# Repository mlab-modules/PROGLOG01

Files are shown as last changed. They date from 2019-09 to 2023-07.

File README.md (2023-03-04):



# PROGLOG01B - Small low-power open-source tool chain compatible FPGA

<!--- Lead --->
Module with a small programmable gate-array [ICE40UP5K](https://www.latticesemi.com/en/Products/FPGAandCPLD/iCE40UltraPlus).
<!--- ELead --->

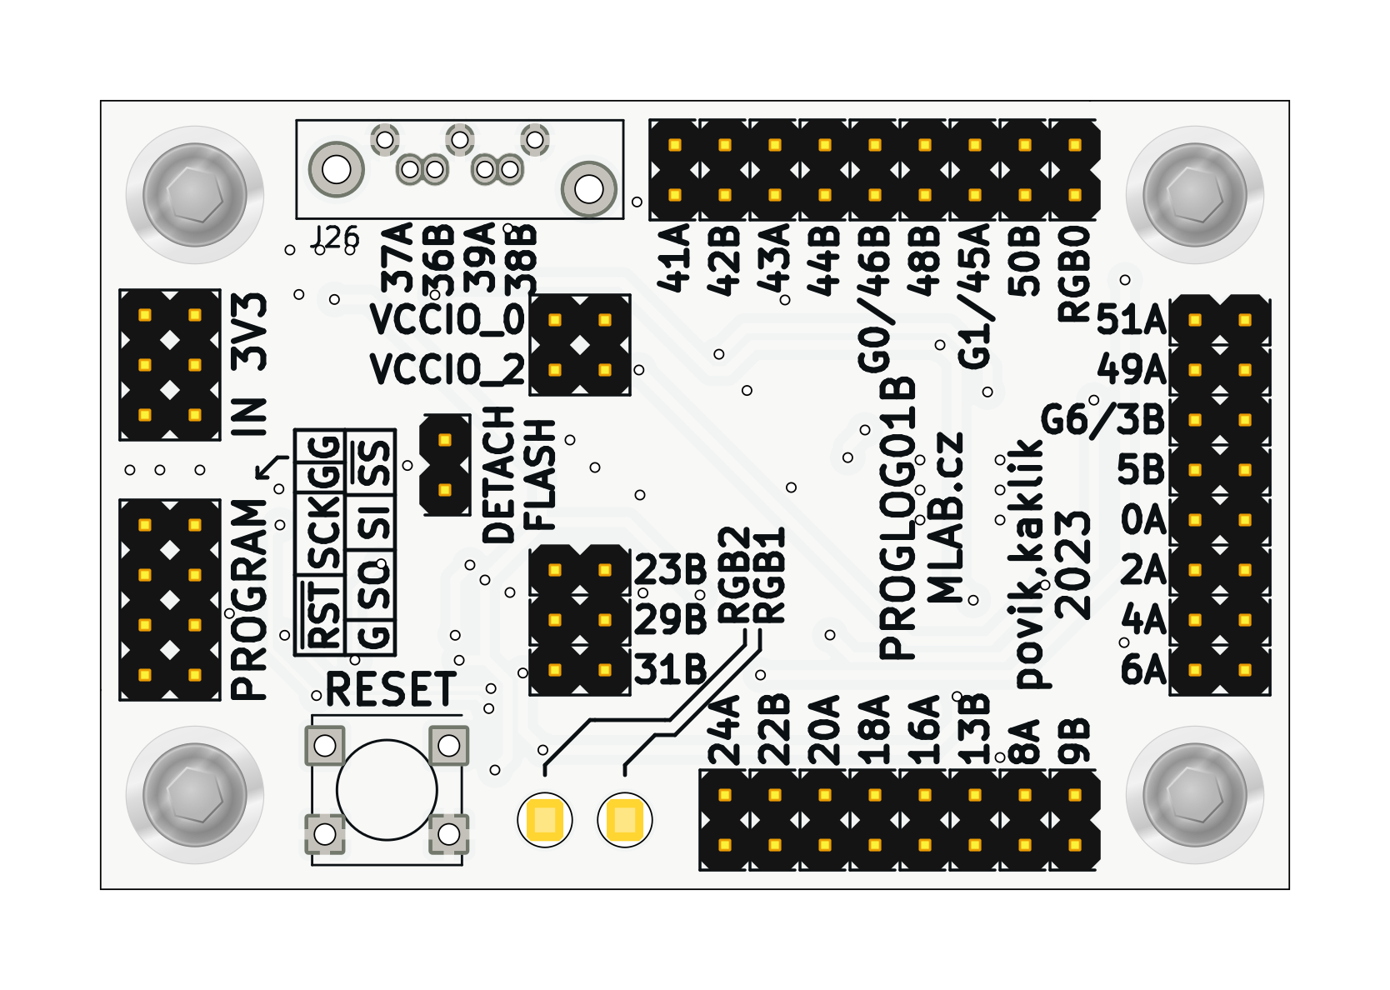
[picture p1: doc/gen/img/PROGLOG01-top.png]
PROGLOG01B top side

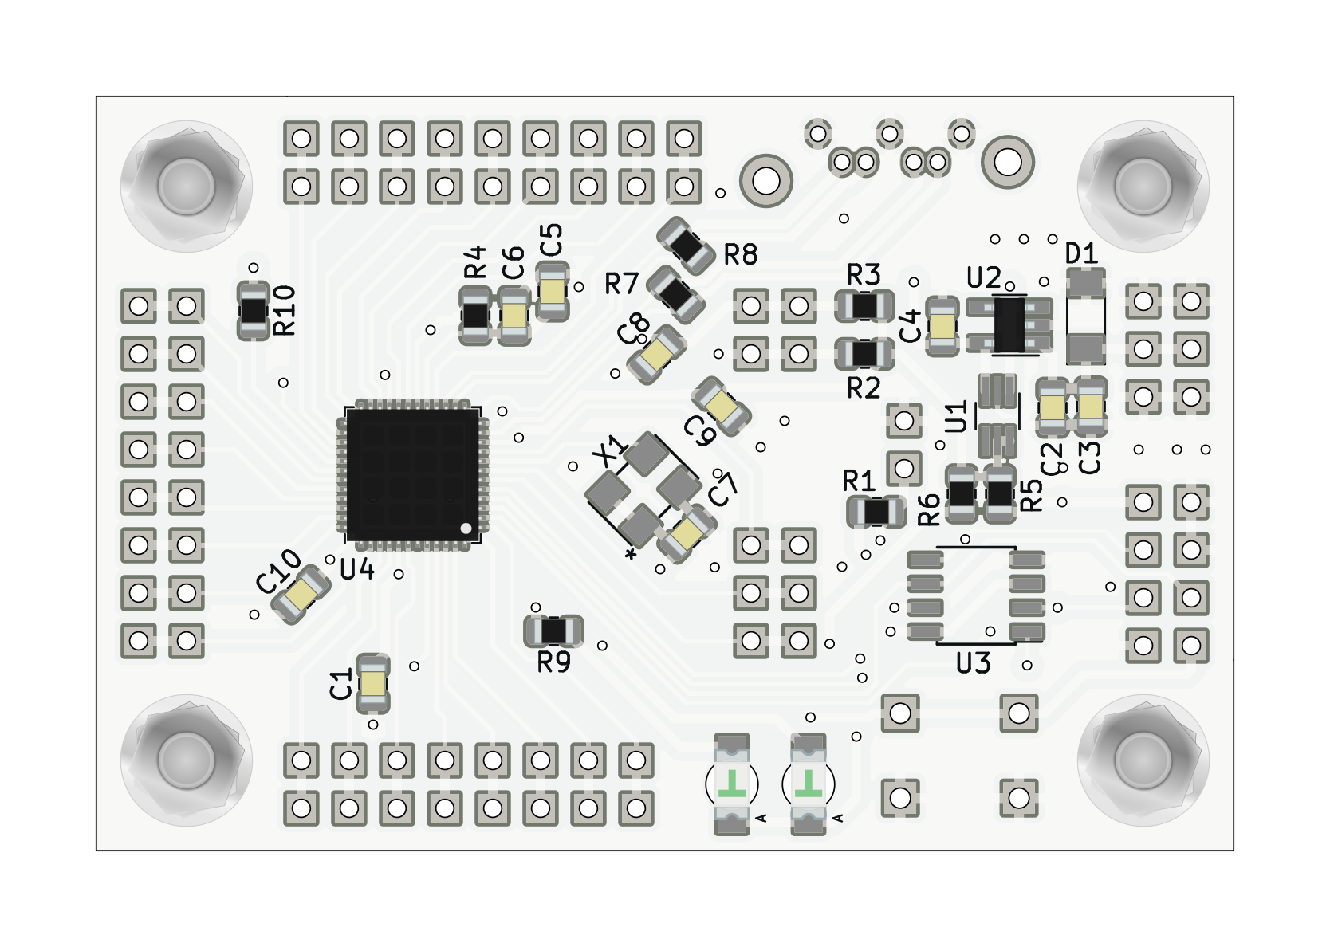
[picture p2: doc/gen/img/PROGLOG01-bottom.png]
PROGLOG01B bottom side


The FPGA module compatible with fully open source toolchains like [symbiflow](https://symbiflow.github.io/).

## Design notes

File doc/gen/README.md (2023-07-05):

# PCB

Board size: 60.45x40.13 mm (2.38x1.58 inches)

- This is the size of the rectangle that contains the board
- Thickness: 1.6 mm (63 mils)
- Material: FR4
- Finish: None
- Layers: 2
- Copper thickness: 35 µm

Solder mask: TOP / BOTTOM

- Color: Green

Silk screen: TOP / BOTTOM

- Color: White

Stackup:

| Name | Type | Color | Thickness | Material | Epsilon_r | Loss tangent |
|---|---|---|---|---|---|---|
| F.SilkS | Top Silk Screen | | | | | |
| F.Paste | Top Solder Paste | | | | | |
| F.Mask | Top Solder Mask | | 10 | | | |
| F.Cu | copper | | 35 | | | |
| dielectric 1 | core | | 1510 | FR4 | 4.5 | 0.020 |
| B.Cu | copper | | 35 | | | |
| B.Mask | Bottom Solder Mask | | 10 | | | |
| B.Paste | Bottom Solder Paste  | | | | | |
| B.SilkS | Bottom Silk Screen | | | | | |

# Important sizes

Clearance: 0.2 mm (8 mils)

Track width: 0.25 mm (10 mils)

- By design rules: 0.25 mm (10 mils)

Drill: 0.5 mm (20 mils)

- Vias: 0.5 mm (20 mils) [Design: 0.4 mm (16 mils)]
- Pads: 0.85 mm (33 mils)
- The above values are real drill sizes, they add 0.1 mm (4 mils) to plated holes (PTH)

Via: 0.8/0.4 mm (31/16 mils)

- By design rules: 0.4/0.3 mm (16/12 mils)
- Micro via: yes [0.2/0.1 mm (8/4 mils)]
- Buried/blind via: yes
- Total: 58 (thru: 58 buried/blind: 0 micro: 0)

Outer Annular Ring: 0.13 mm (5 mils)

- By design rules: 0.13 mm (5 mils)

Eurocircuits class: 6B
- Using min drill 0.5 mm for an OAR of 0.13 mm

# General stats

Components count: (SMD/THT)

- Top: 0/38 (THT)
- Bottom: 27/1 (SMD + THT)

Defined tracks:

- 0.25 mm (10 mils)
- 0.5 mm (20 mils)

Used tracks:

- 0.25 mm (10 mils) (244) defined: yes
- 0.4 mm (16 mils) (14) defined: no
- 0.5 mm (20 mils) (217) defined: yes

Defined vias:

Used vias:

- 0.8/0.4 mm (31/16 mils) (Count: 58, Aspect: 2.0 A) defined: no

Holes (excluding vias):

- 0.74 mm (29 mils) (7)
- 0.89 mm (35 mils) (76)
- 1.0 mm (39 mils) (4)
- 1.35 mm (53 mils) (2)
- 2.7 mm (106 mils) (2)
- 3.0 mm (118 mils) (4)

Oval holes:

Drill tools (including vias and computing adjusts and rounding):

- 0.5 mm (20 mils) (58)
- 0.85 mm (33 mils) (7)
- 1.0 mm (39 mils) (76)
- 1.1 mm (43 mils) (4)
- 1.45 mm (57 mils) (2)
- 2.7 mm (106 mils) (2)
- 3.1 mm (122 mils) (4)

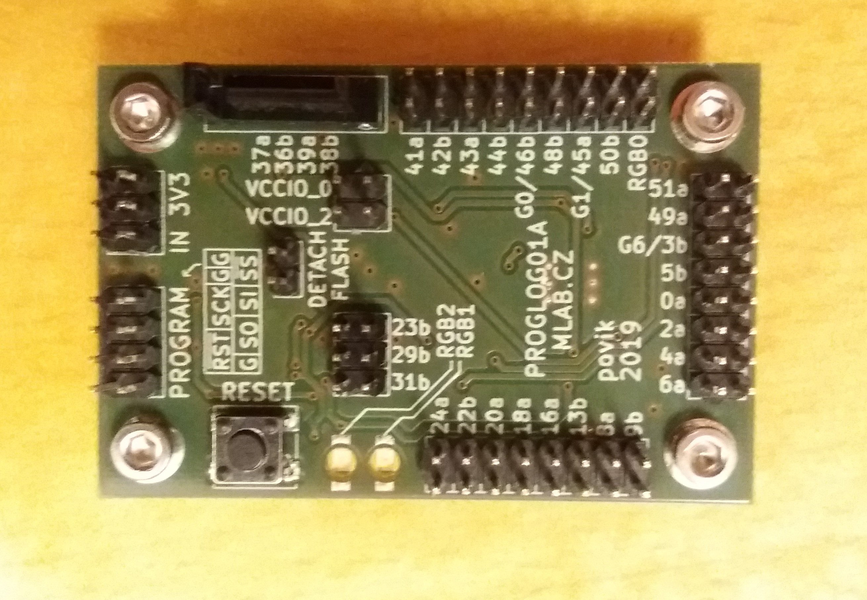
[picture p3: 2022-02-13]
doc/img/PROGLOG01A_top_big.jpg

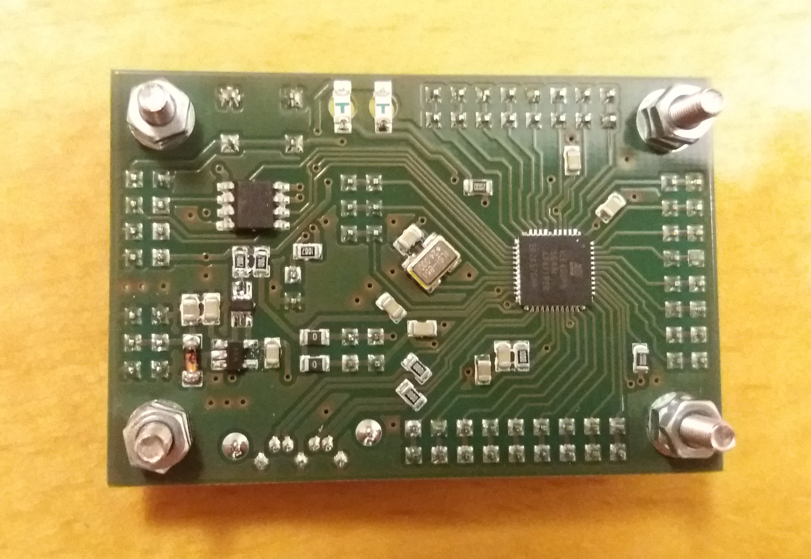
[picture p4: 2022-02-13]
doc/img/PROGLOG01A_bot_big.jpg

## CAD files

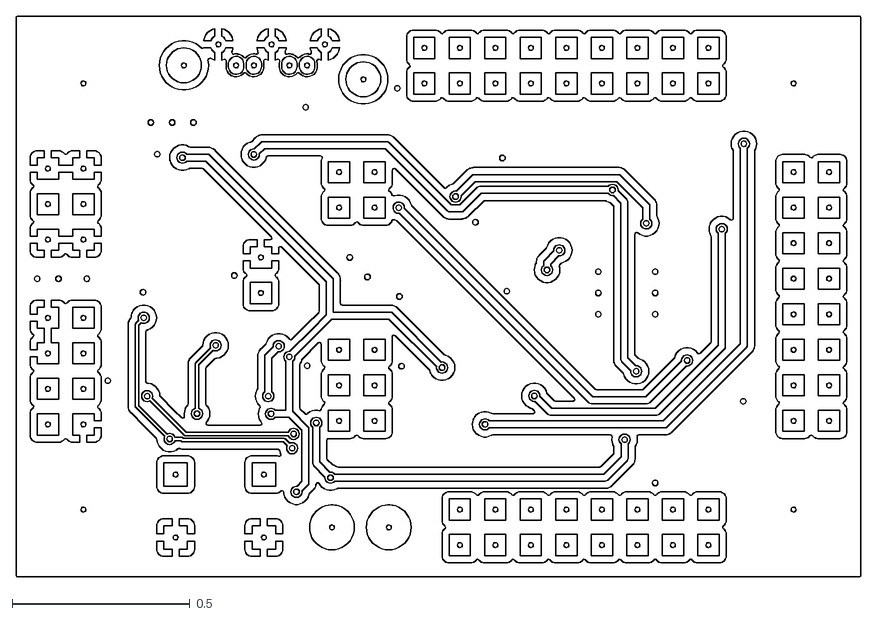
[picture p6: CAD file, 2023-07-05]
doc/gen/dxf/PROGLOG01-F_Cu.dxf
2.38 x 1.58

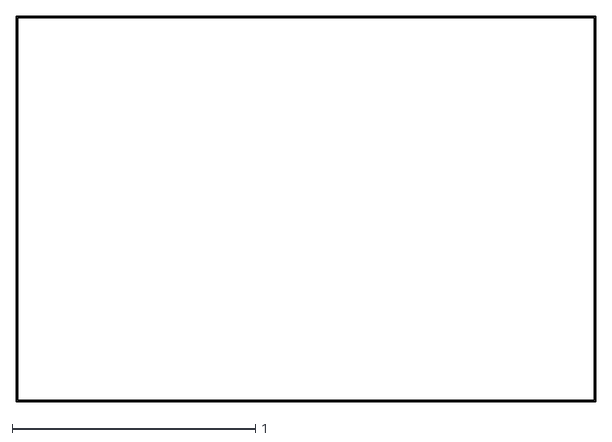
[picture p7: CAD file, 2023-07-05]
doc/gen/dxf/PROGLOG01-Edge_Cuts.dxf
2.39 x 1.59

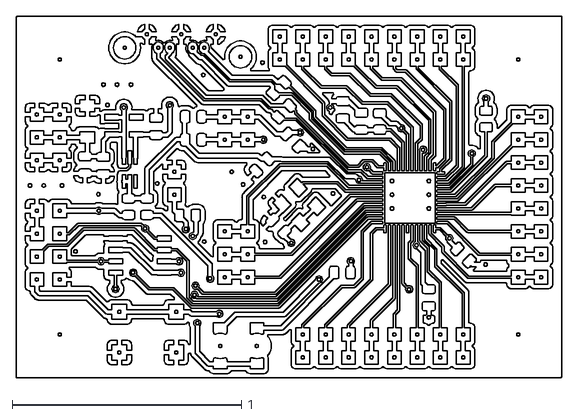
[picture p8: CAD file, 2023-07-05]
doc/gen/dxf/PROGLOG01-B_Cu.dxf
2.38 x 1.58

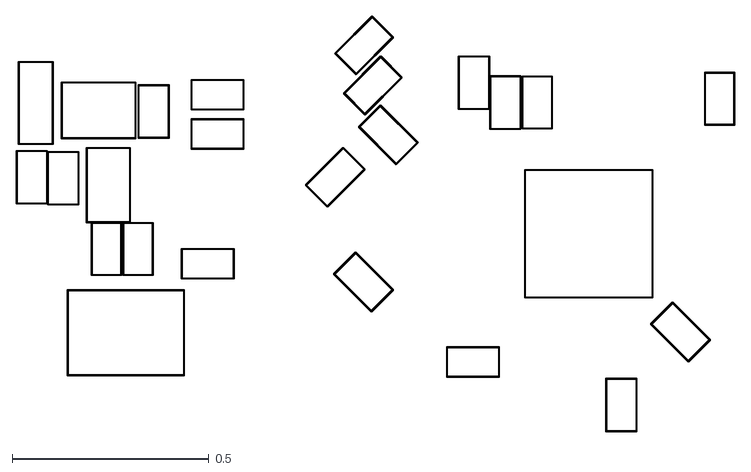
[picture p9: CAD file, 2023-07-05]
doc/gen/dxf/PROGLOG01-B_Courtyard.dxf
1.83 x 1.06

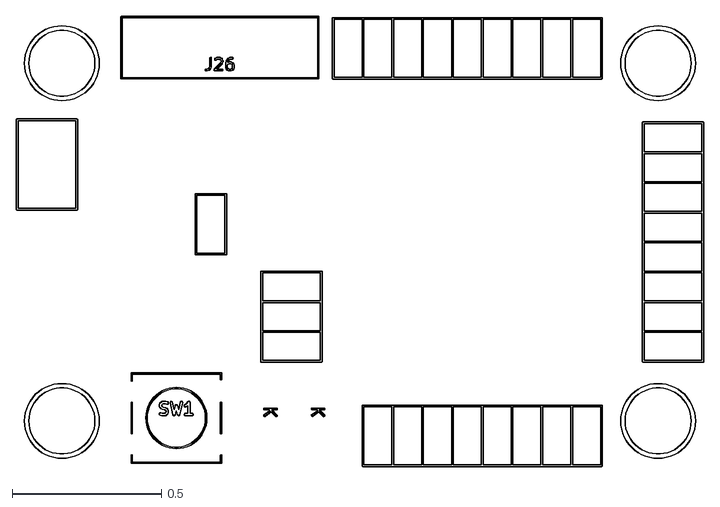
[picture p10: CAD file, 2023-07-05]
doc/gen/dxf/PROGLOG01-F_Fab.dxf
2.31 x 1.51

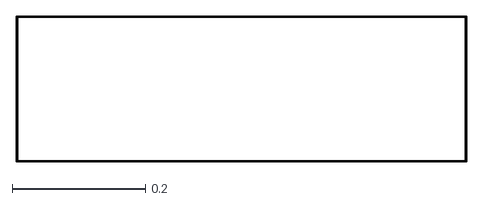
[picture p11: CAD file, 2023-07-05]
doc/gen/dxf/PROGLOG01-F_Courtyard.dxf
0.675 x 0.219

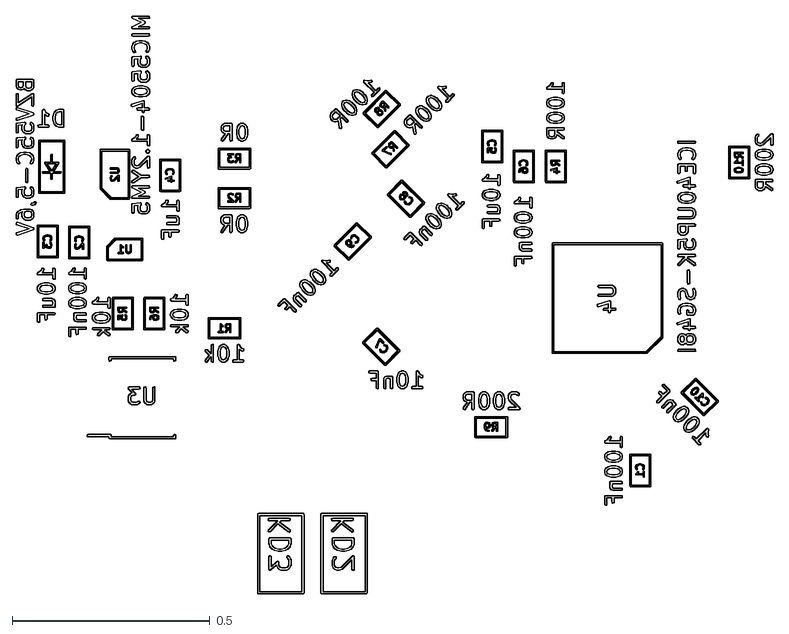
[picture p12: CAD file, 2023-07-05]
doc/gen/dxf/PROGLOG01-B_Fab.dxf
1.92 x 1.46

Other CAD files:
doc/gen/dxf/PROGLOG01-Margin.dxf
doc/gen/dxf/PROGLOG01-B_Mask.dxf
doc/gen/dxf/PROGLOG01-B_Paste.dxf
doc/gen/dxf/PROGLOG01-B_Silkscreen.dxf
doc/gen/dxf/PROGLOG01-F_Mask.dxf
doc/gen/dxf/PROGLOG01-F_Paste.dxf
doc/gen/dxf/PROGLOG01-F_Silkscreen.dxf

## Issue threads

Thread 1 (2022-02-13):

Prohozené signály u Flash paměti

kaklik, 2022-02-13:
Je potřeba zkontrolovat, jestli je to opravené i v layoutu a vytvořit revizi B.

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

povik, 2022-02-13:
Neni to opravené.

kaklik, 2022-11-16:
Pokusil jsem se v [datasheetu](https://www.latticesemi.com/-/media/LatticeSemi/Documents/DataSheets/iCE/FPGA-DS-02008-1-9-iCE40-UltraPlus-Family-Data-Sheet.ashx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) najít, jaký je pinout konfiguračního SPI rozhraní, které má být připojeno k SPI flash.

Nepodařilo se mi však najít více než tohle, což neobjasňuje proč jsou nyní piny zapojeny špatně. Současné zapojení ale odpovídá popiskům nožiček na schématických značkách. Tudíž očekávám že k opravě chyby je potřeba opravit schematickou značku FPGA, neboť schematická značka SPI flash je správně. To jsem již podle datasheetu zkontroloval.

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

Chěl jsem to opravit, aby bylo možné vyrobit více kusů modulů a celý další vývoj nestál pouze na existujících dvou kusech.

kaklik, 2023-02-19:
@povik  Tak jsem to myslím si opravil. Mohl bys akorát prosím zkontrolovat, že je to opravené dobře? Na fotografii totiž jsou celkem tři provizorní drátky, ale našel jsem jen dvě prohozená místa. Třetí myslím vede na stejný pin jako původní cestička. To byla nějaká chyba při změně zapojení?

povik, 2023-02-20:
Jo, prohozené ve schématu 01A jsou jen dva dráty u paměti (MISO/MOSI). Že jsou na tom operovaném kusu tři drátky, bude kvůli nějakému omylu při přepojování.

> Tudíž očekávám že k opravě chyby je potřeba opravit schematickou značku FPGA, neboť schematická značka SPI flash je správně.

Jak tohle dopadlo? Čekám, že to byla chyba ve schématu, né ve značce, tak si to pamatuju.

kaklik, 2023-02-20:
> > Tudíž očekávám že k opravě chyby je potřeba opravit schematickou značku FPGA, neboť schematická značka SPI flash je správně.
>
> Jak tohle dopadlo? Čekám, že to byla chyba ve schématu, né ve značce, tak si to pamatuju.

S tímhle to teď je tak, že ta schématická značka FPGA je neopravená. Tj. je pravděpodobně špatně název pinu ve schématické značce. Kontroloval jsem to podle čísla pinu, které je myslím si správně.

povik, 2023-02-20:
> S tímhle to teď je tak, že ta schématická značka FPGA je neopravená. Tj. je pravděpodobně špatně název pinu ve schématické značce. Kontroloval jsem to podle čísla pinu, které je myslím si správně.

Ne, já myslim, že značka je správně. Jen je matoucí, že pin SI/SO na součástce hradlovýho pole znamená Serial In/Out, nikoliv Slave In/Out, takže se to s pamětí musí zapojit křížem. To je původ toho omylu ve schématu.

kaklik, 2023-02-20:
> Ne, já myslim, že značka je správně. Jen je matoucí, že pin SI/SO na součástce hradlovýho pole znamená Serial In/Out, nikoliv Slave In/Out, takže se to s pamětí musí zapojit křížem. To je původ toho omylu ve schématu.

Aha, tak to je opravdu matoucí.  To by si možná zasloužilo nějakou poznámku do schéma. Protože se to děsně blbě ověřuje. V datasheetu jsem totiž tohle našel jen na jednom místě a nedošlo mi z toho, že to není chyba v datasheetu.

Closed 2023-02-19.

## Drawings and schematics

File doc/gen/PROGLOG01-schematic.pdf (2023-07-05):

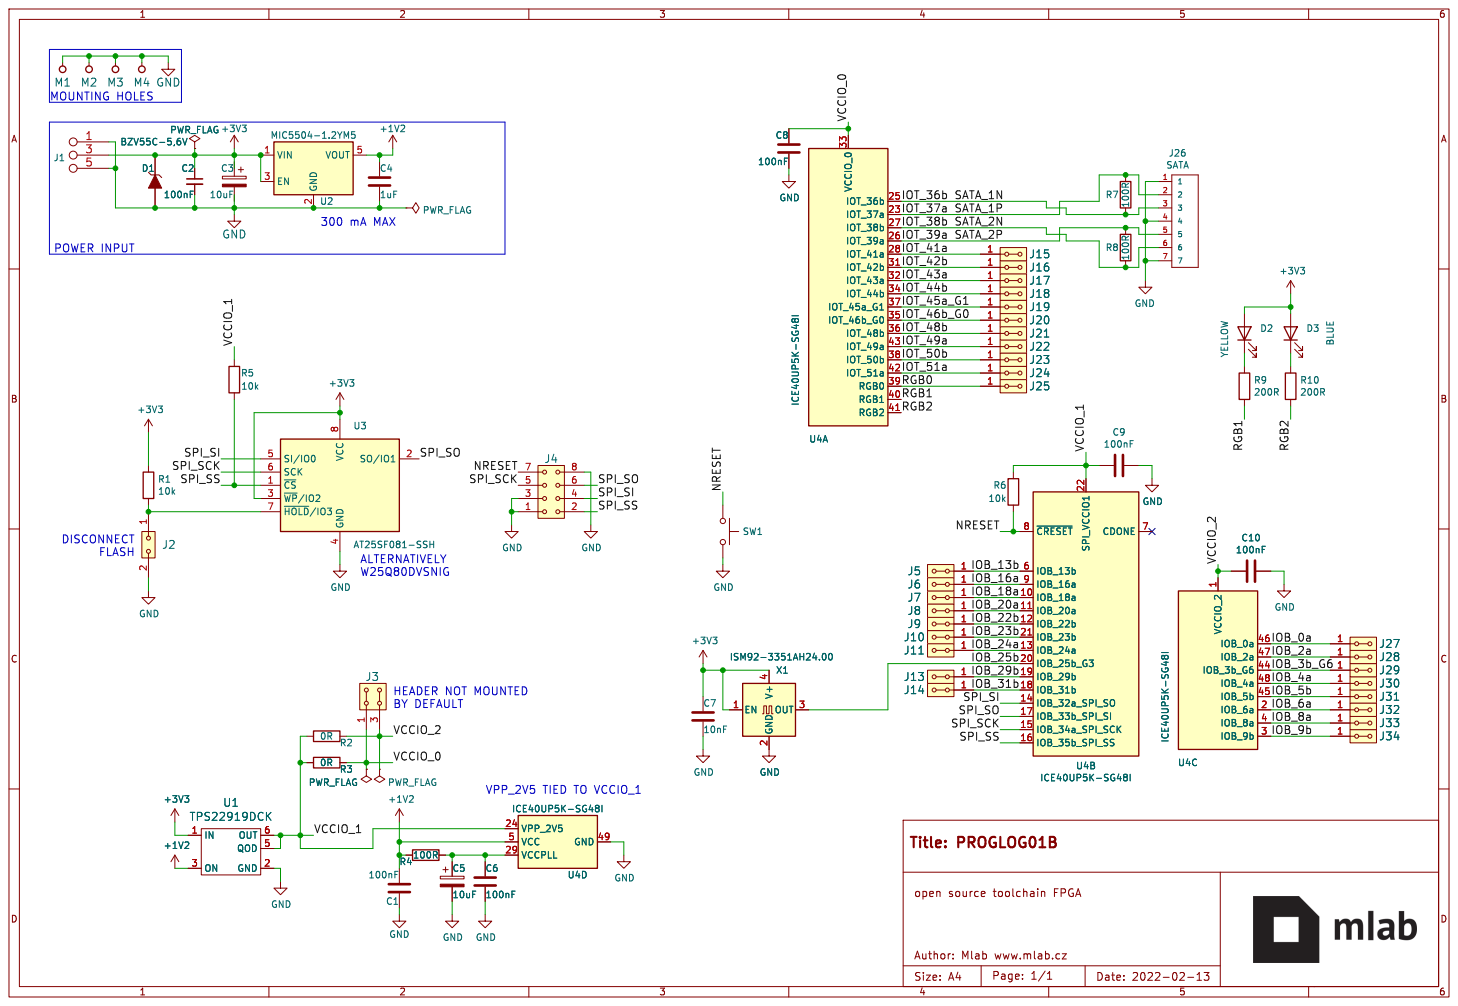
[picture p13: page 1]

POWER INPUT MOUNTING HOLES

4 SI/IO0 5 SCK 6 ~{HOLD}/IO3 7 VCC

VPP_2V5 TIED TO VCCIO_1 HEADER NOT MOUNTED

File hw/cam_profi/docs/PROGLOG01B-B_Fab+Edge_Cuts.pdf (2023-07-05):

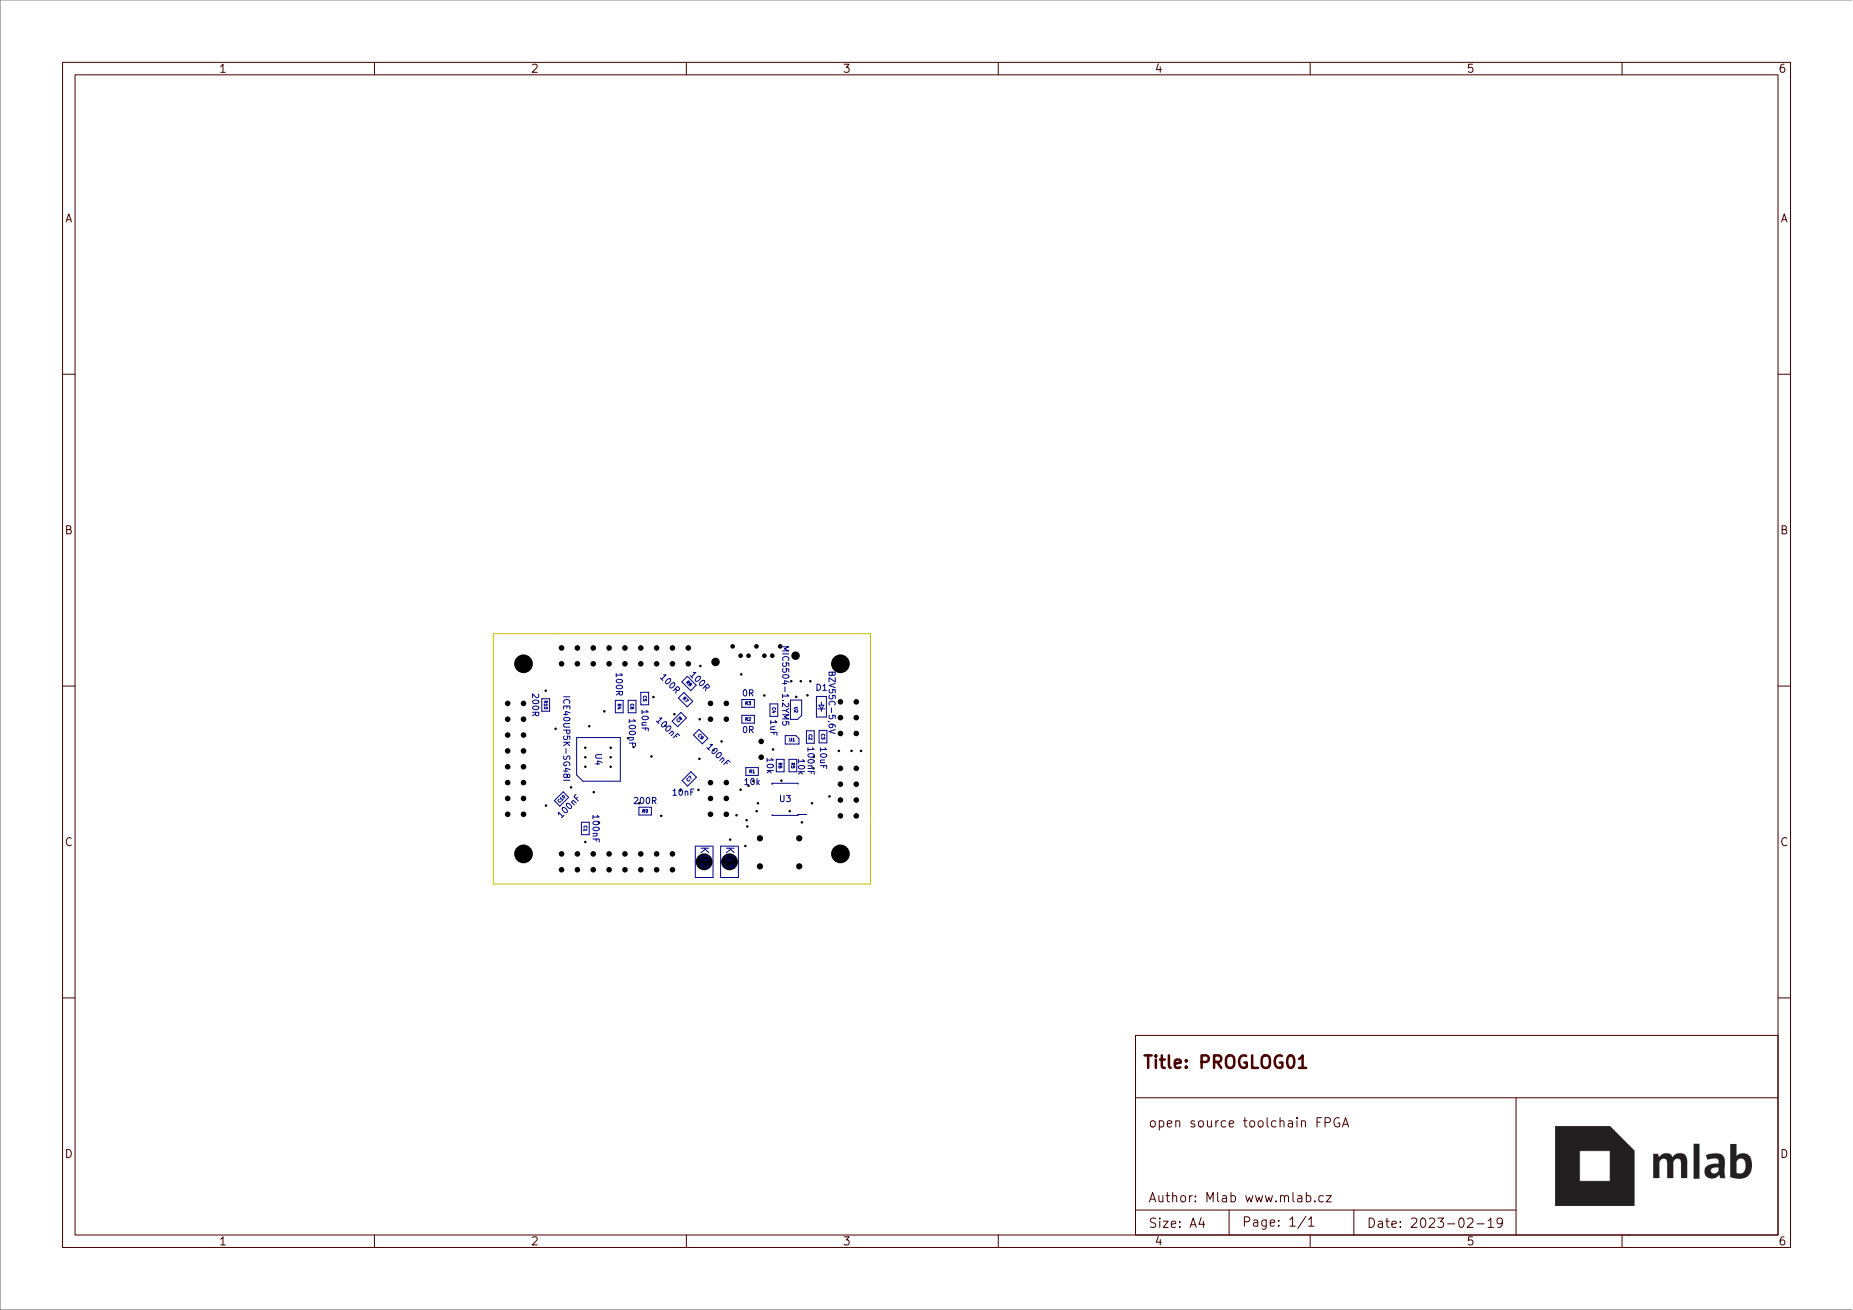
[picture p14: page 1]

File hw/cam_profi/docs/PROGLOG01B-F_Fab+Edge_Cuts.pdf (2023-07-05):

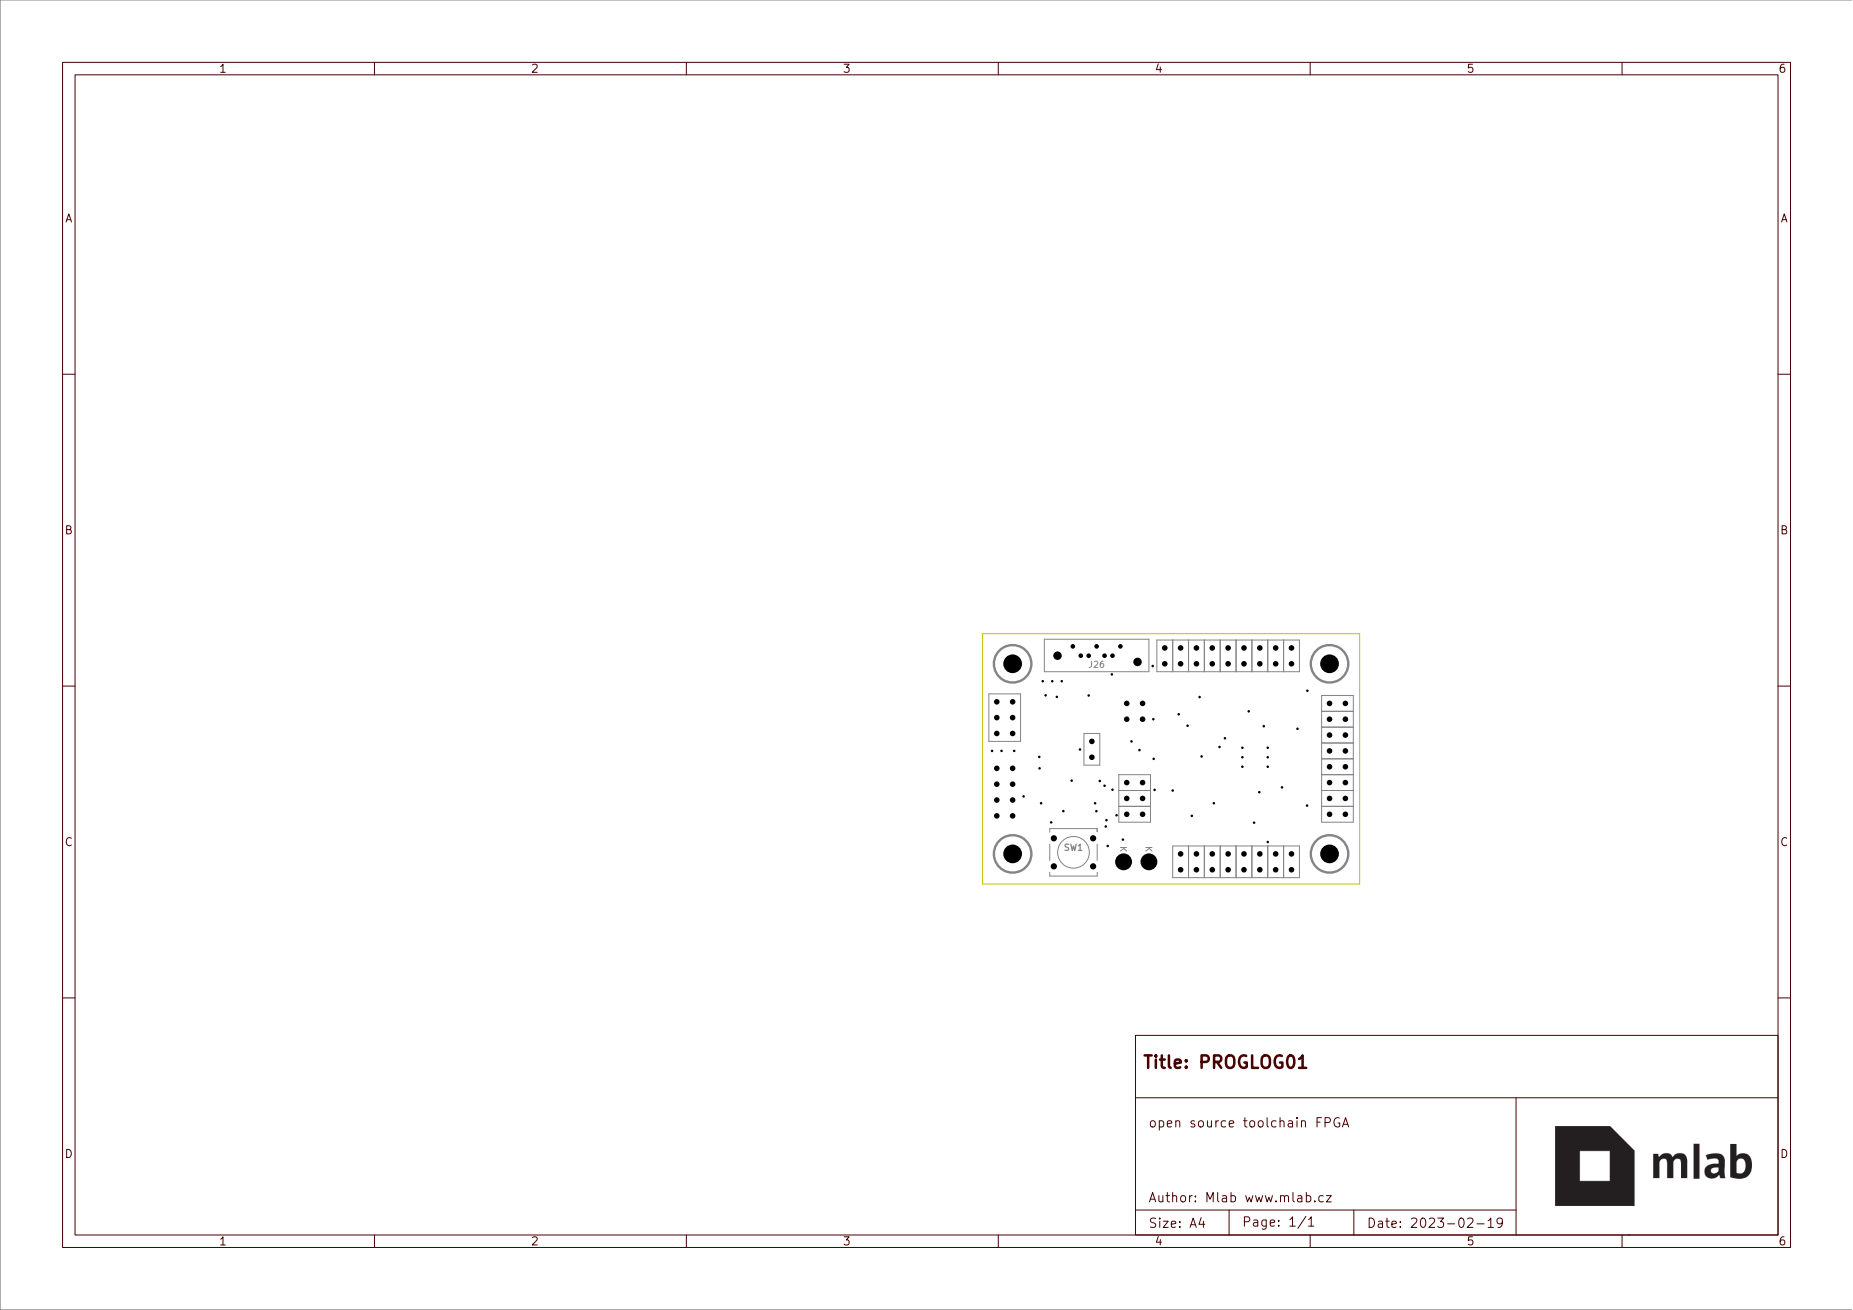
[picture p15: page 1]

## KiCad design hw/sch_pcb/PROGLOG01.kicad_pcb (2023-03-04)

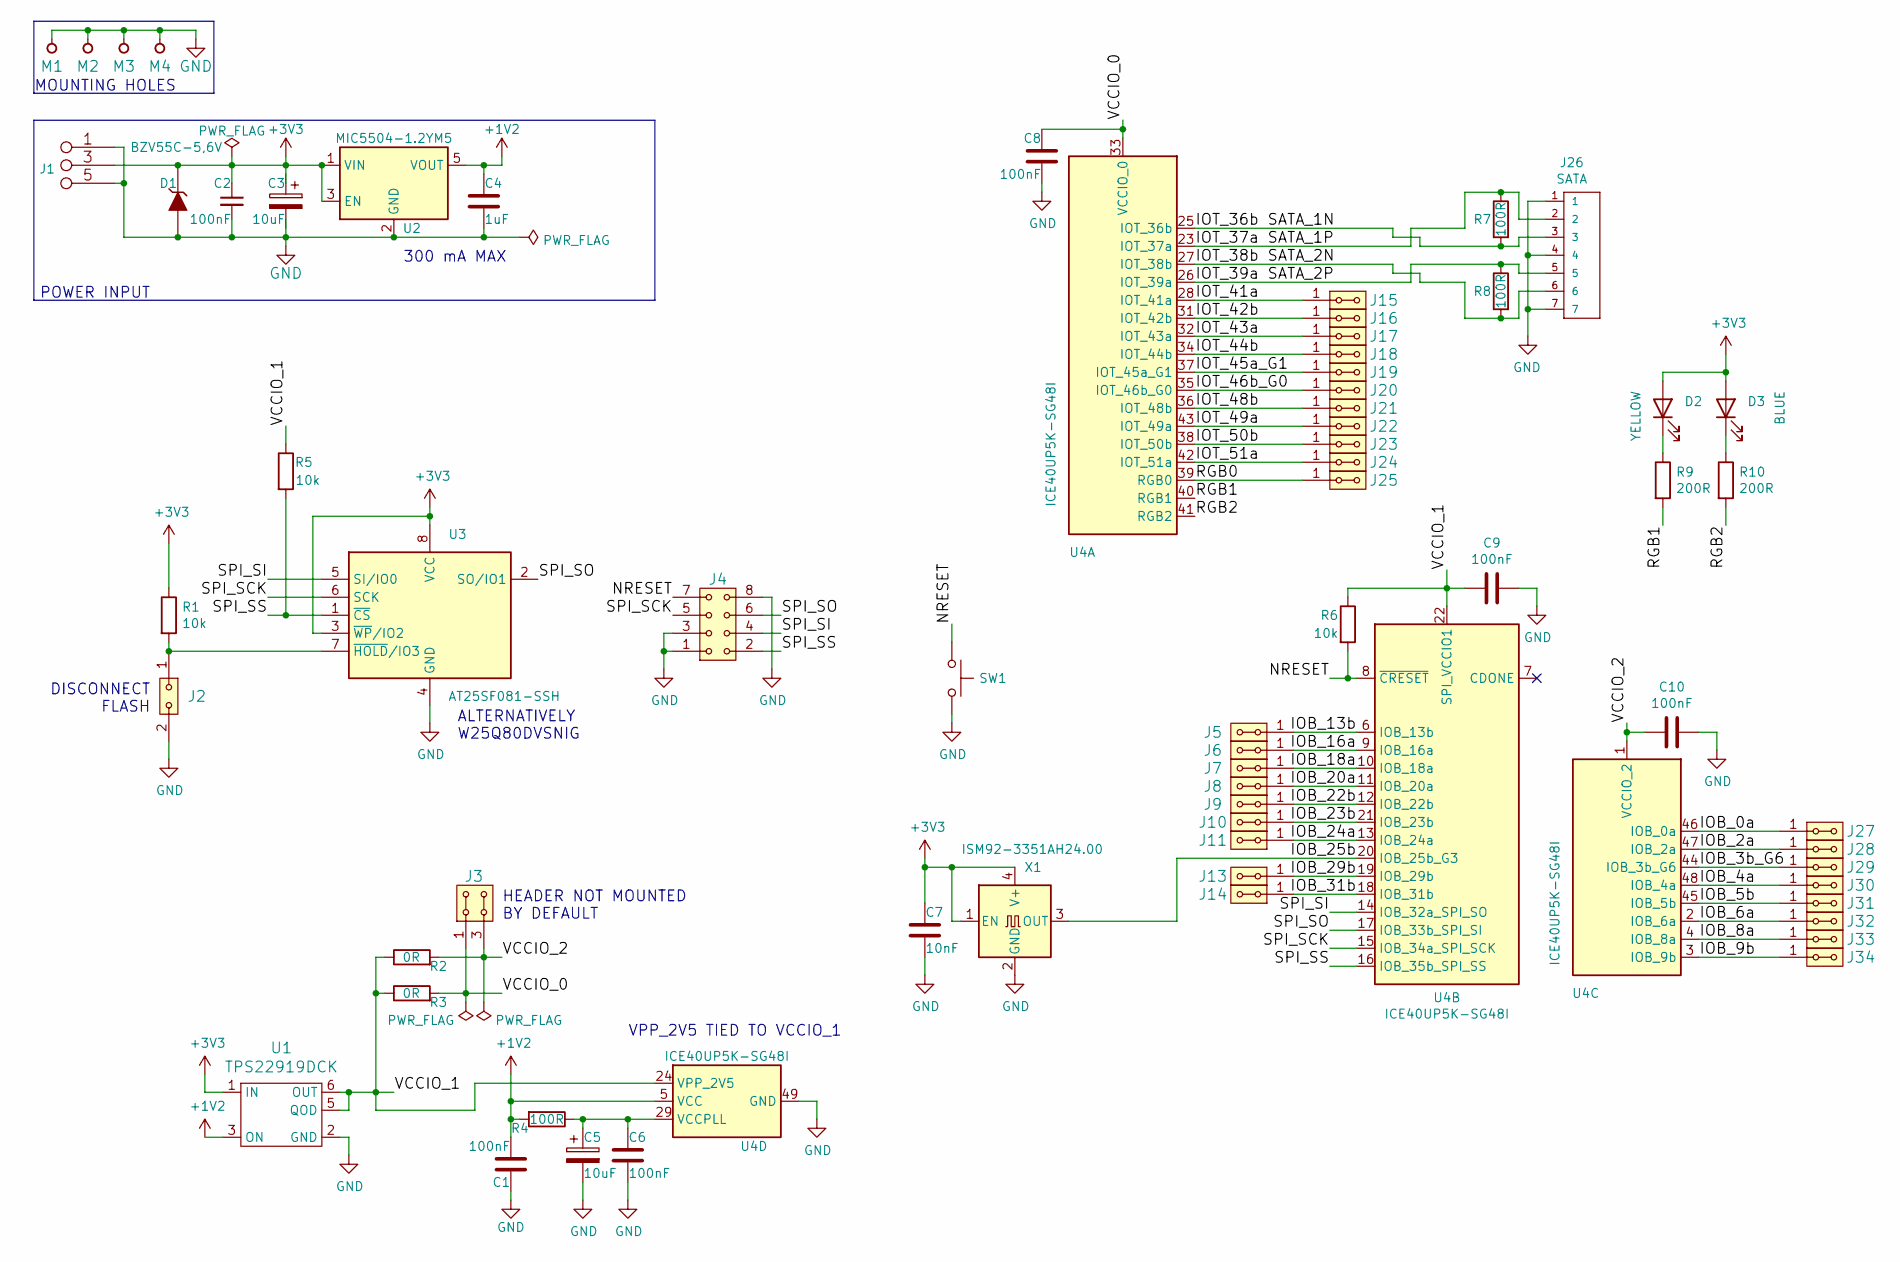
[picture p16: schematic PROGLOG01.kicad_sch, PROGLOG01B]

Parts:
C1, C2, C6, C8, C9, C10: 100nF; C_0805_2012Metric
C3, C5: 10uF; C_0805_2012Metric
C4: 1uF; C_0805_2012Metric
C7: 10nF; C_0805_2012Metric
D1: BZV55C-5,6V; Diode-MiniMELF_Standard
D2: YELLOW; LED_1206
D3: BLUE; LED_1206
J1: JUMP_3X2; Straight_2x03
J2: HEADER_2x01; Straight_2x01
J3: HEADER_2x02_PARALLEL; Straight_2x02
J4: HEADER_2x04; Straight_2x04
J5, J6, J7, J8, J9, J10, J11, J13, J14, J15, J16, J17, J18, J19, J20, J21, J22, J23, J24, J25, J27, J28, J29, J30, J31, J32, J33, J34: HEADER_2x01_PARALLEL; Straight_2x01
J26: SATA; MOLEX_67491-1030
M1, M2, M3, M4: HOLE; MountingHole_3mm
R1, R5, R6: 10k; R_0805_2012Metric
R2, R3: 0R; R_0805_2012Metric
R4, R7, R8: 100R; R_0805_2012Metric
R9, R10: 200R; R_0805_2012Metric
SW1: SW_Push; SW_PUSH_SMALL
U1: TPS22919DCK; SOT-363_SC-70-6_Handsoldering
U2: MIC5504-1.2YM5; SOT-23-5
U3: AT25SF081-SSH; SOIC-8_3.9x4.9mm_P1.27mm
U4: ICE40UP5K-SG48I; QFN-48-1EP_7x7mm_P0.5mm_EP5.6x5.6mm
X1: ISM92-3351AH24.00; Oscillator_SMD_EuroQuartz_XO91-4Pin_7.0x5.0mm

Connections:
+1V2: C1.2, C4.1, R4.2, U1.3 (ON), U2.5 (VOUT), U4.5 (VCC), U4.30 (VCC)
+3V3: C2.1, C3.1, C7.1, D1.1 (K), D2.2 (A), D3.2 (A), J1.3 (4), J1.4, R1.1, U1.1 (IN), U2.1 (VIN), U2.3 (EN), U3.3 (~WP/IO2), U3.8 (VCC), X1.1 (EN), X1.4 (V+)
/IOB_0a: J27.1, J27.2, U4.46 (IOB_0a)
/IOB_2a: J28.1, J28.2, U4.47 (IOB_2a)
/IOB_3b_G6: J29.1, J29.2, U4.44 (IOB_3b_G6)
/IOB_4a: J30.1, J30.2, U4.48 (IOB_4a)
/IOB_5b: J31.1, J31.2, U4.45 (IOB_5b)
/IOB_6a: J32.1, J32.2, U4.2 (IOB_6a)
/IOB_8a: J33.1, J33.2, U4.4 (IOB_8a)
/IOB_9b: J34.1, J34.2, U4.3 (IOB_9b)
/IOB_13b: J5.1, J5.2, U4.6 (IOB_13b)
/IOB_16a: J6.1, J6.2, U4.9 (IOB_16a)
/IOB_18a: J7.1, J7.2, U4.10 (IOB_18a)
/IOB_20a: J8.1, J8.2, U4.11 (IOB_20a)
/IOB_22b: J9.1, J9.2, U4.12 (IOB_22b)
/IOB_23b: J10.1, J10.2, U4.21 (IOB_23b)
/IOB_24a: J11.1, J11.2, U4.13 (IOB_24a)
/IOB_25b: U4.20 (IOB_25b_G3), X1.3 (OUT)
/IOB_29b: J13.1, J13.2, U4.19 (IOB_29b)
/IOB_31b: J14.1, J14.2, U4.18 (IOB_31b)
/IOT_36b: J26.3, R7.2, U4.25 (IOT_36b)
/IOT_37a: J26.2, R7.1, U4.23 (IOT_37a)
/IOT_38b: J26.6, R8.2, U4.27 (IOT_38b)
/IOT_39a: J26.5, R8.1, U4.26 (IOT_39a)
/IOT_41a: J15.1, J15.2, U4.28 (IOT_41a)
/IOT_42b: J16.1, J16.2, U4.31 (IOT_42b)
/IOT_43a: J17.1, J17.2, U4.32 (IOT_43a)
/IOT_44b: J18.1, J18.2, U4.34 (IOT_44b)
/IOT_45a_G1: J19.1, J19.2, U4.37 (IOT_45a_G1)
/IOT_46b_G0: J20.1, J20.2, U4.35 (IOT_46b_G0)
/IOT_48b: J21.1, J21.2, U4.36 (IOT_48b)
/IOT_49a: J22.1, J22.2, U4.43 (IOT_49a)
/IOT_50b: J23.1, J23.2, U4.38 (IOT_50b)
/IOT_51a: J24.1, J24.2, U4.42 (IOT_51a)
/NRESET: J4.7, R6.2, SW1.1, U4.8 (~CRESET)
/RGB0: J25.1, J25.2, U4.39 (RGB0)
/RGB1: R9.2, U4.40 (RGB1)
/RGB2: R10.2, U4.41 (RGB2)
/SPI_SCK: J4.5, U3.6 (SCK), U4.15 (IOB_34a_SPI_SCK)
/SPI_SI: J4.4, U3.5 (SI/IO0), U4.14 (IOB_32a_SPI_SO)
/SPI_SO: J4.6, U3.2 (SO/IO1), U4.17 (IOB_33b_SPI_SI)
/SPI_SS: J4.2, R5.2, U3.1 (~CS), U4.16 (IOB_35b_SPI_SS)
/VCCIO_0: C8.1, J3.1, J3.2, R3.2, U4.33 (VCCIO_0)
/VCCIO_1: C9.2, R2.1, R3.1, R5.1, R6.1, U1.5 (QOD), U1.6 (OUT), U4.22 (SPI_VCCIO1), U4.24 (VPP_2V5)
/VCCIO_2: C10.2, J3.3, J3.4, R2.2, U4.1 (VCCIO_2)
GND: C1.1, C2.2, C3.2, C4.2, C5.2, C6.2, C7.2, C8.2, C9.1, C10.1, D1.2 (A), J1.1 (2), J1.2, J1.5 (6), J1.6, J2.2, J4.1, J4.3, J4.8, J26.1, J26.4, J26.7, M1.1, M2.1, M3.1, M4.1, SW1.2, U1.2 (GND), U2.2 (GND), U3.4 (GND), U4.49 (GND), X1.2 (GND)
unnamed: C5.1, C6.1, R4.1, U4.29 (VCCPLL)
unnamed: D2.1 (K), R9.1
unnamed: D3.1 (K), R10.1
unnamed: J2.1, R1.2, U3.7 (~HOLD/IO3)

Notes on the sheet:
HEADER NOT MOUNTED BY DEFAULT
VPP_2V5 TIED TO VCCIO_1
MOUNTING HOLES
DISCONNECT FLASH
300 mA MAX
POWER INPUT
ALTERNATIVELY W25Q80DVSNIG

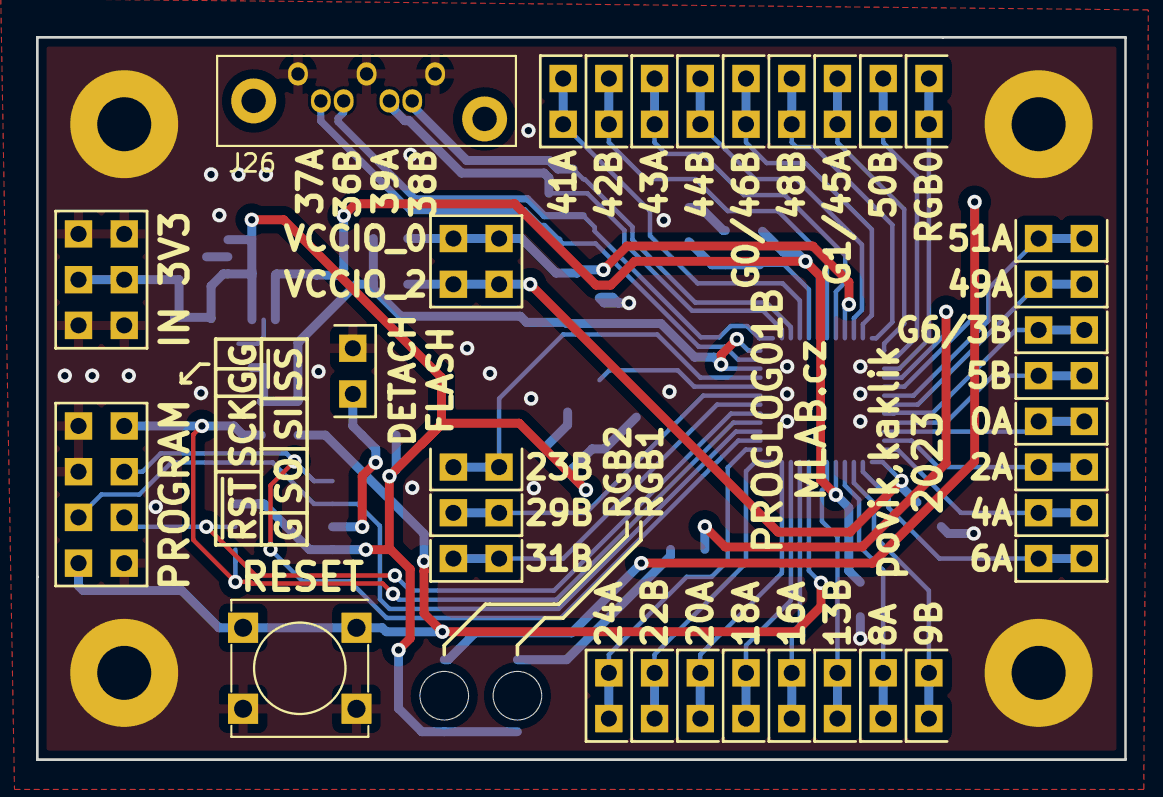
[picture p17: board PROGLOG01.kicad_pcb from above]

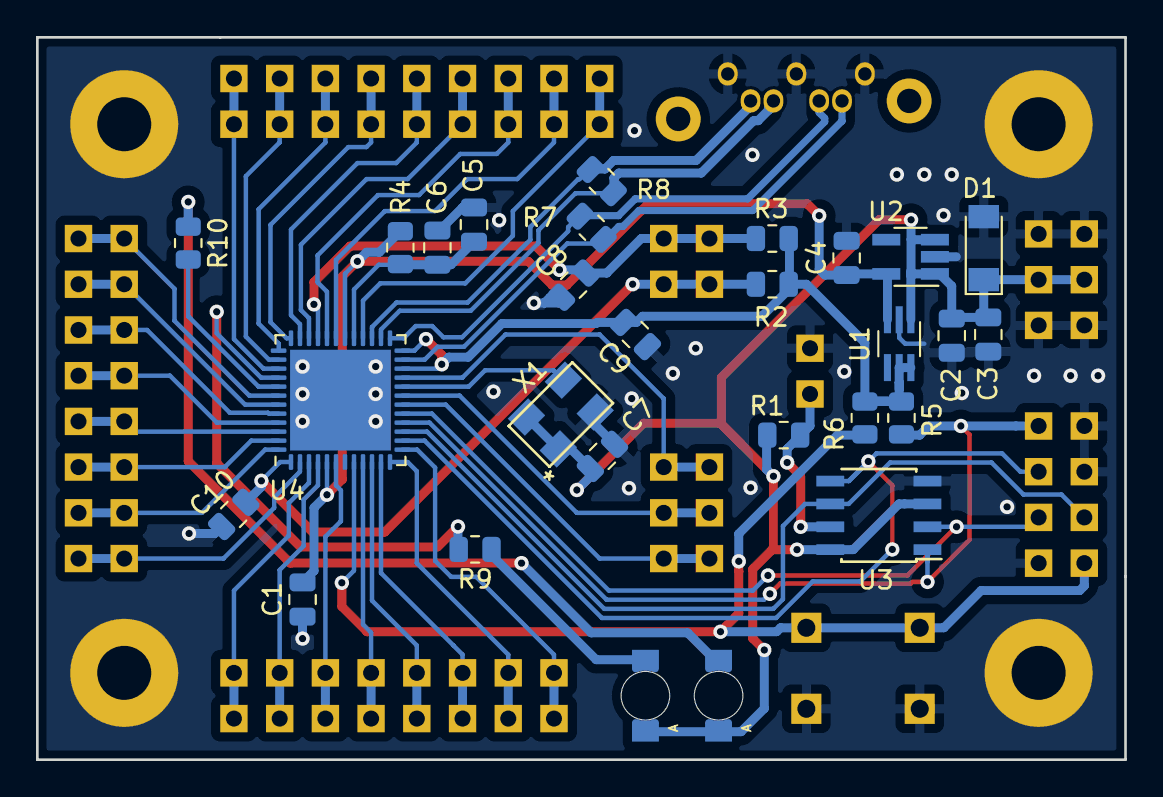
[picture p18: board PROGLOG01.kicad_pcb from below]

Board: 2 copper layers, 60.5 x 40.1 mm, 66 parts (28 on the bottom side), 50 nets.

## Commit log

2019-09-25 Initialize PROGLOG01A with a preliminary schema
    [PROGLOG01A.kicad_pcb, PROGLOG01A.sch]
2019-09-25 Fix supplies in PROGLOG01A schematics
    [PROGLOG01A.sch]
2019-09-25 Fix supplies in PROGLOG01A schematic
    [PROGLOG01A.sch]
2019-10-09 Progress on PROGLOG01A
    [PROGLOG01A.sch]
2019-10-13 Make changes to PROGLOG01A schematic
    [PROGLOG01A.sch]
2019-10-14 Change footprints and make a minor fix
    [PROGLOG01A.sch]
2019-10-22 Start drawing, make some fixes to schematic
    [PROGLOG01A.kicad_pcb, PROGLOG01A.sch]
2019-10-28 Progress on drawing, change schematic
    [PROGLOG01A.kicad_pcb, PROGLOG01A.sch]
2019-11-04 Fix layout issues
    [PROGLOG01A.kicad_pcb]
2019-11-08 Generovana vyrobni data
    [PROGLOG01A-B_Cu.gbr, PROGLOG01A-B_Mask.gbr, PROGLOG01A-Edge_Cuts.gbr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]
2019-11-14 Uprava dat pro osazovani
    [PROGLOG01A.kicad_pcb]
2022-02-13 Documentation update. Project updated to kicad 6.0.1.
    [PROGLOG01A.kicad_pcb, PROGLOG01A.kicad_sch]
2022-02-13 repository cleanup Removing old KiCAD project files.
    [PROGLOG01A.sch]
2022-04-06 Update actions products
    [PROGLOG01A-B_Courtyard.dxf, PROGLOG01A-B_Cu.dxf, PROGLOG01A-B_Fab.dxf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]
2022-11-16 Start a work on updated, fixed version.
    [PROGLOG01B.kicad_pcb, PROGLOG01B.kicad_sch]
2023-02-19 Rename project to revision neutral name.
    [PROGLOG01.kicad_pcb, PROGLOG01.kicad_sch]
2023-02-19 Update project and documentation.
    [PROGLOG01.kicad_pcb, PROGLOG01.kicad_sch]
2023-02-19 Fix unconnected tracks DRC errors.
    [PROGLOG01.kicad_pcb]
2023-02-19 Repair #1 in schematics.
    [PROGLOG01.kicad_sch]
2023-02-19 Fix #1 Layout improvement vias position improvement.
    [PROGLOG01.kicad_pcb]
2023-03-02 Imrove layout - avoid sharp edges.
    [PROGLOG01.kicad_pcb]
2023-03-03 Update footprints from library. Improve bottom silkscreen.
    [PROGLOG01.kicad_pcb, PROGLOG01.kicad_sch]
2023-03-03 Resolve DRC errors in silkscreen.
    [PROGLOG01.kicad_pcb]
2023-03-03 Resolve silkscreen and layout issues.
    [PROGLOG01.kicad_pcb]
2023-03-03 Fix wrong UST_ID assigned.
    [PROGLOG01.kicad_pcb, PROGLOG01.kicad_sch]
2023-03-03 Update actions scripts Cleanup B.Fab layer.
    [PROGLOG01.kicad_pcb]
2023-03-04 Update schematics symbols.
    [PROGLOG01.kicad_sch]
2023-03-04 Add a link to datasheet.
    [PROGLOG01.kicad_sch]
2023-03-04 Improve B.Fab readability.
    [PROGLOG01.kicad_pcb]
